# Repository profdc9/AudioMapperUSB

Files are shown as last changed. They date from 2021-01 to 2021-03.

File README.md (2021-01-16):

# AudioMapper USB by Daniel Marks

This project is to develop a simple device for characterizing the audio characteristics of a room.  It is intended to be used 

It is based on the PCM2900/PCM2902 TI USB CODEC DAC/ADC.  It has the following features:

- Amplification for two microphone inputs (up to a gain of 125 or 42 dB gain).  The gain stages may be jumpered out if desired to provide a standard line input.
- Phantom power provided to microphone inputs (10 kohm resistor for 5 volts) so that electret or dynamic microphones may be used.
- DAC is 44.1 kHz/48 kHz 16-bit stereo output.
- ADC is 44.1 kHz/48 kHz 16-bit stereo input.
- Can sample the outputs back to the input for synchronizing the audio output signal to the audio input signal.
- Several boards may be chained together to synchronize them.
- A provision for external power input so that the USB power noise (especially USB traffic) does not produce noise on the microphone inputs.  It is recommended that a 9-12 VDC linear power supply is used.
- SPDIF input and outputs.
- Feedback resistors can be surface mount or through hole for easy gain adjustments.

The kicad files and gerbers are provided.  The project is licensed under the Creative Common License, CC-BY-SA 4.0.

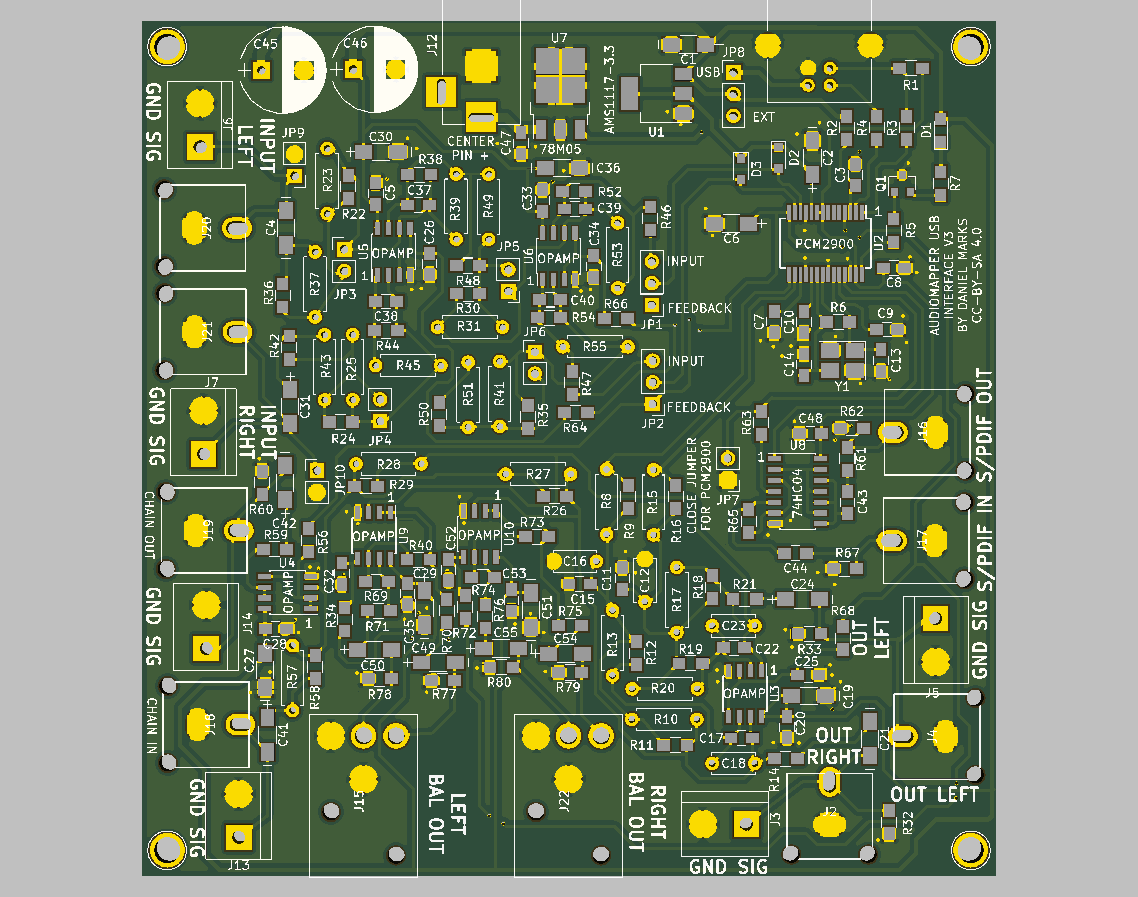
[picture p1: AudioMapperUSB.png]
PCB


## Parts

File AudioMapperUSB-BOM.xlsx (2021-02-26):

Comment | Designator | Footprint | LCSC
18 pF | C14,C13 | Capacitors_SMD:C_0805_HandSoldering | C1797
1.5 nF | C15,C11 | Capacitors_SMD:C_0805_HandSoldering | C1717
330 pF | C17,C22 | Capacitors_SMD:C_0805_HandSoldering | C51207
NO | C18,C16,C23,C12 | Capacitors_THT:C_Disc_D5.0mm_W2.5mm_P5.00mm | C51207
10 uF | C2,C1,C6,C4,C19,C21,C24,C27,C30,C31,C36,C42,C41 | AudioMapperUSB:CP_1206_HandSoldering | C7171
1 uF | C3,C8,C10,C7,C20,C25,C28,C5,C34,C33,C9,C43,C44,C47,C48,C26 | Capacitors_SMD:C_0805_HandSoldering | C28323
22 pF | C38,C37 | Capacitors_SMD:C_0805_HandSoldering | C1804
100 pF | C40,C39 | Capacitors_SMD:C_0805_HandSoldering | C1790
1000 uF | C46,C45 | Capacitors_THT:CP_Radial_D10.0mm_P5.00mm
LED | D1 | LEDs:LED_0805_HandSoldering | C84256
1N4148WS | D2,D3 | Diodes_SMD:D_SOD-323_HandSoldering | C2128
USB_B | J1 | Connectors:USB_B
Jack-DC | J12 | Connectors:BARREL_JACK
Audio-Jack-2 | J2,J4,J16,J17,J18,J19,J20,J21 | AudioMapperUSB:RCAConnectorCommon
Conn_01x02 | J3,J5,J6,J7,J13,J14 | Connectors_Terminal_Blocks:TerminalBlock_bornier-2_P5.08mm
Conn_01x01 | J8,J10,J11,J9 | Connectors:1pin
Jumper_NC_Dual | JP2,JP1,JP8 | Pin_Headers:Pin_Header_Straight_1x03_Pitch2.54mm
Jumper_NC_Small | JP7,JP3,JP4,JP5,JP6 | Pin_Headers:Pin_Header_Straight_1x02_Pitch2.54mm
Jumper_NO_Small | JP9,JP10 | Pin_Headers:Pin_Header_Straight_1x02_Pitch2.54mm
SS8550 | Q1 | TO_SOT_Packages_SMD:SOT-23 | C8542
1k5 | R1,R5,R7,R46,R47,R56 | Resistors_SMD:R_0805_HandSoldering | C4310
3k9 | R12,R19 | Resistors_SMD:R_0805_HandSoldering | C17614
100R | R14,R21,R59,R62,R67 | Resistors_SMD:R_0805_HandSoldering | C17408
2R2 | R2 | Resistors_SMD:R_0805_HandSoldering | C17521
10k | R26,R29,R65 | Resistors_SMD:R_0805_HandSoldering | C17414
22R | R3,R4 | Resistors_SMD:R_0805_HandSoldering | C17561
18k | R30,R35 | Resistors_SMD:R_0805_HandSoldering | C17506
4k7 | R36,R42,R48,R50,R58 | Resistors_SMD:R_0805_HandSoldering | C17673
100k | R38,R44,R22,R24,R64,R66,R68 | Resistors_SMD:R_0805_HandSoldering | C17407
22k | R52,R54 | Resistors_SMD:R_0805_HandSoldering | C17560
1M | R6,R32,R33,R60 | Resistors_SMD:R_0805_HandSoldering | C17514
220R | R61 | Resistors_SMD:R_0805_HandSoldering | C17557
1k | R63 | Resistors_SMD:R_0805_HandSoldering | C17513
NO | R8,R13,R10,R15,R20,R17,R27,R28,R37,R39,R43,R45,R49,R53,R51,R55,R57,R23,R25,R31,R41 | Resistors_THT:R_Axial_DIN0207_L6.3mm_D2.5mm_P7.62mm_Horizontal
12K | R9,R11,R16,R18 | Resistors_SMD:R_0805_HandSoldering | C17444
AMS1117-3.3 | U1 | TO_SOT_Packages_SMD:SOT-223-3_TabPin2 | C6186
PCM2900 | U2 | Housings_SSOP:SSOP-28_5.3x10.2mm_Pitch0.65mm | C180425
OPA2170 | U3,U4,U5,U6 | Housings_SOIC:SOIC-8_3.9x4.9mm_Pitch1.27mm | C157708 (https://lcsc.com/product-detail/Low-Noise-OpAmps_Gainsil-GS8722-SR_C157708.html/?href=jlc-SMT)
KA78M05_TO252 | U7 | TO_SOT_Packages_SMD:TO-252-3_TabPin2 | C58069
74HC04 | U8 | Housings_SOIC:SOIC-14_3.9x8.7mm_Pitch1.27mm | C5590
12 MHz | Y1 | Crystals:Crystal_SMD_3225-4pin_3.2x2.5mm_HandSoldering | C9002

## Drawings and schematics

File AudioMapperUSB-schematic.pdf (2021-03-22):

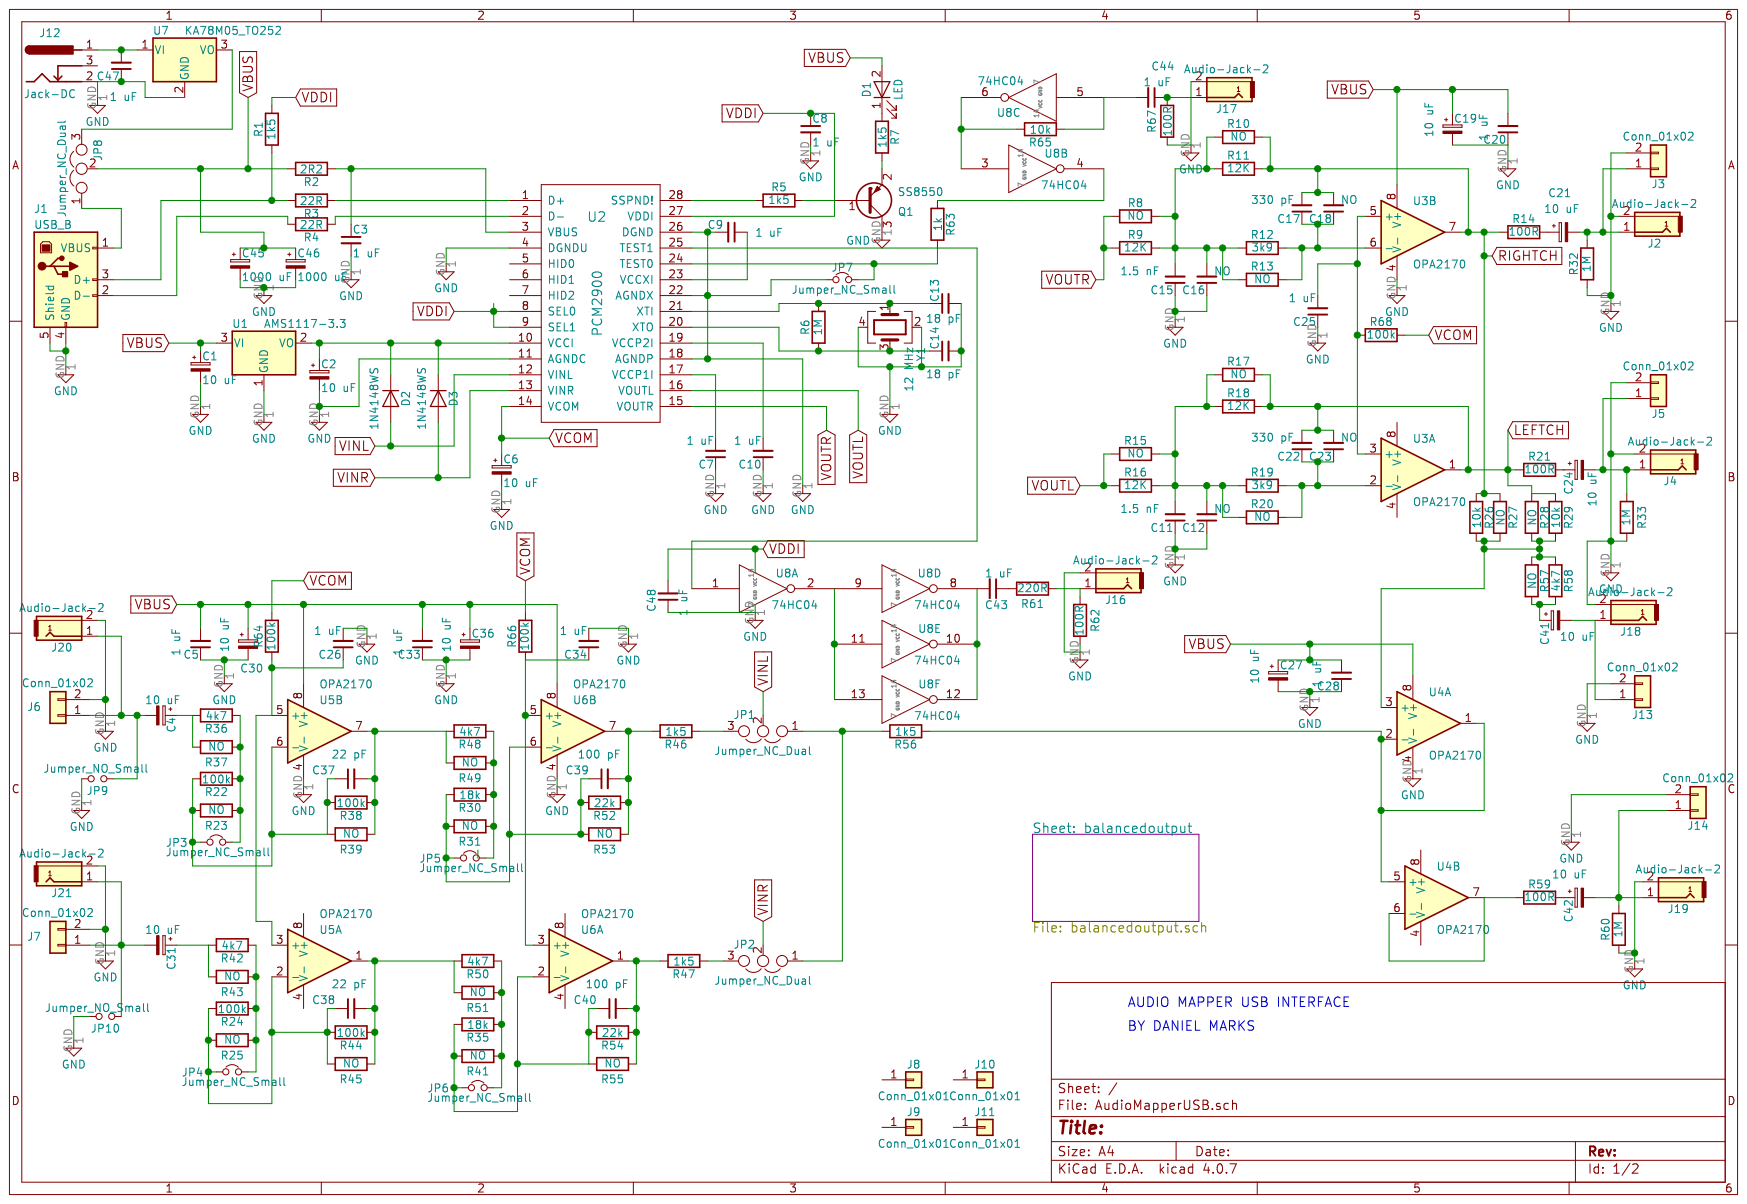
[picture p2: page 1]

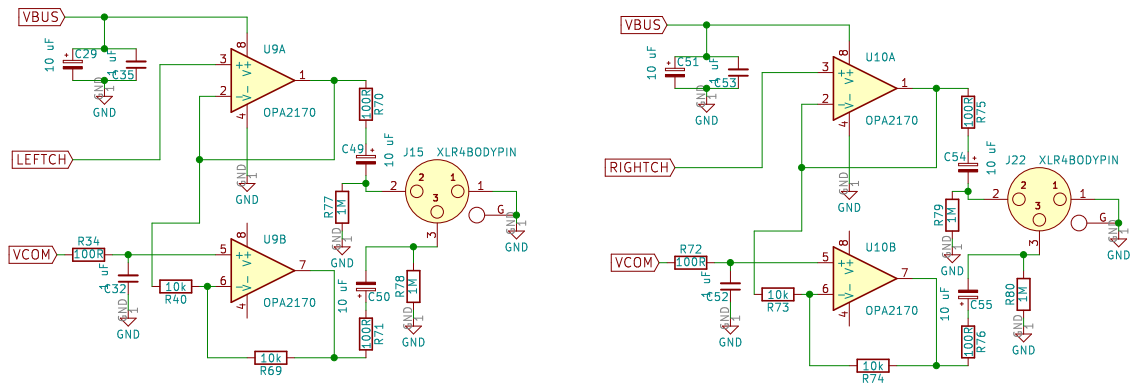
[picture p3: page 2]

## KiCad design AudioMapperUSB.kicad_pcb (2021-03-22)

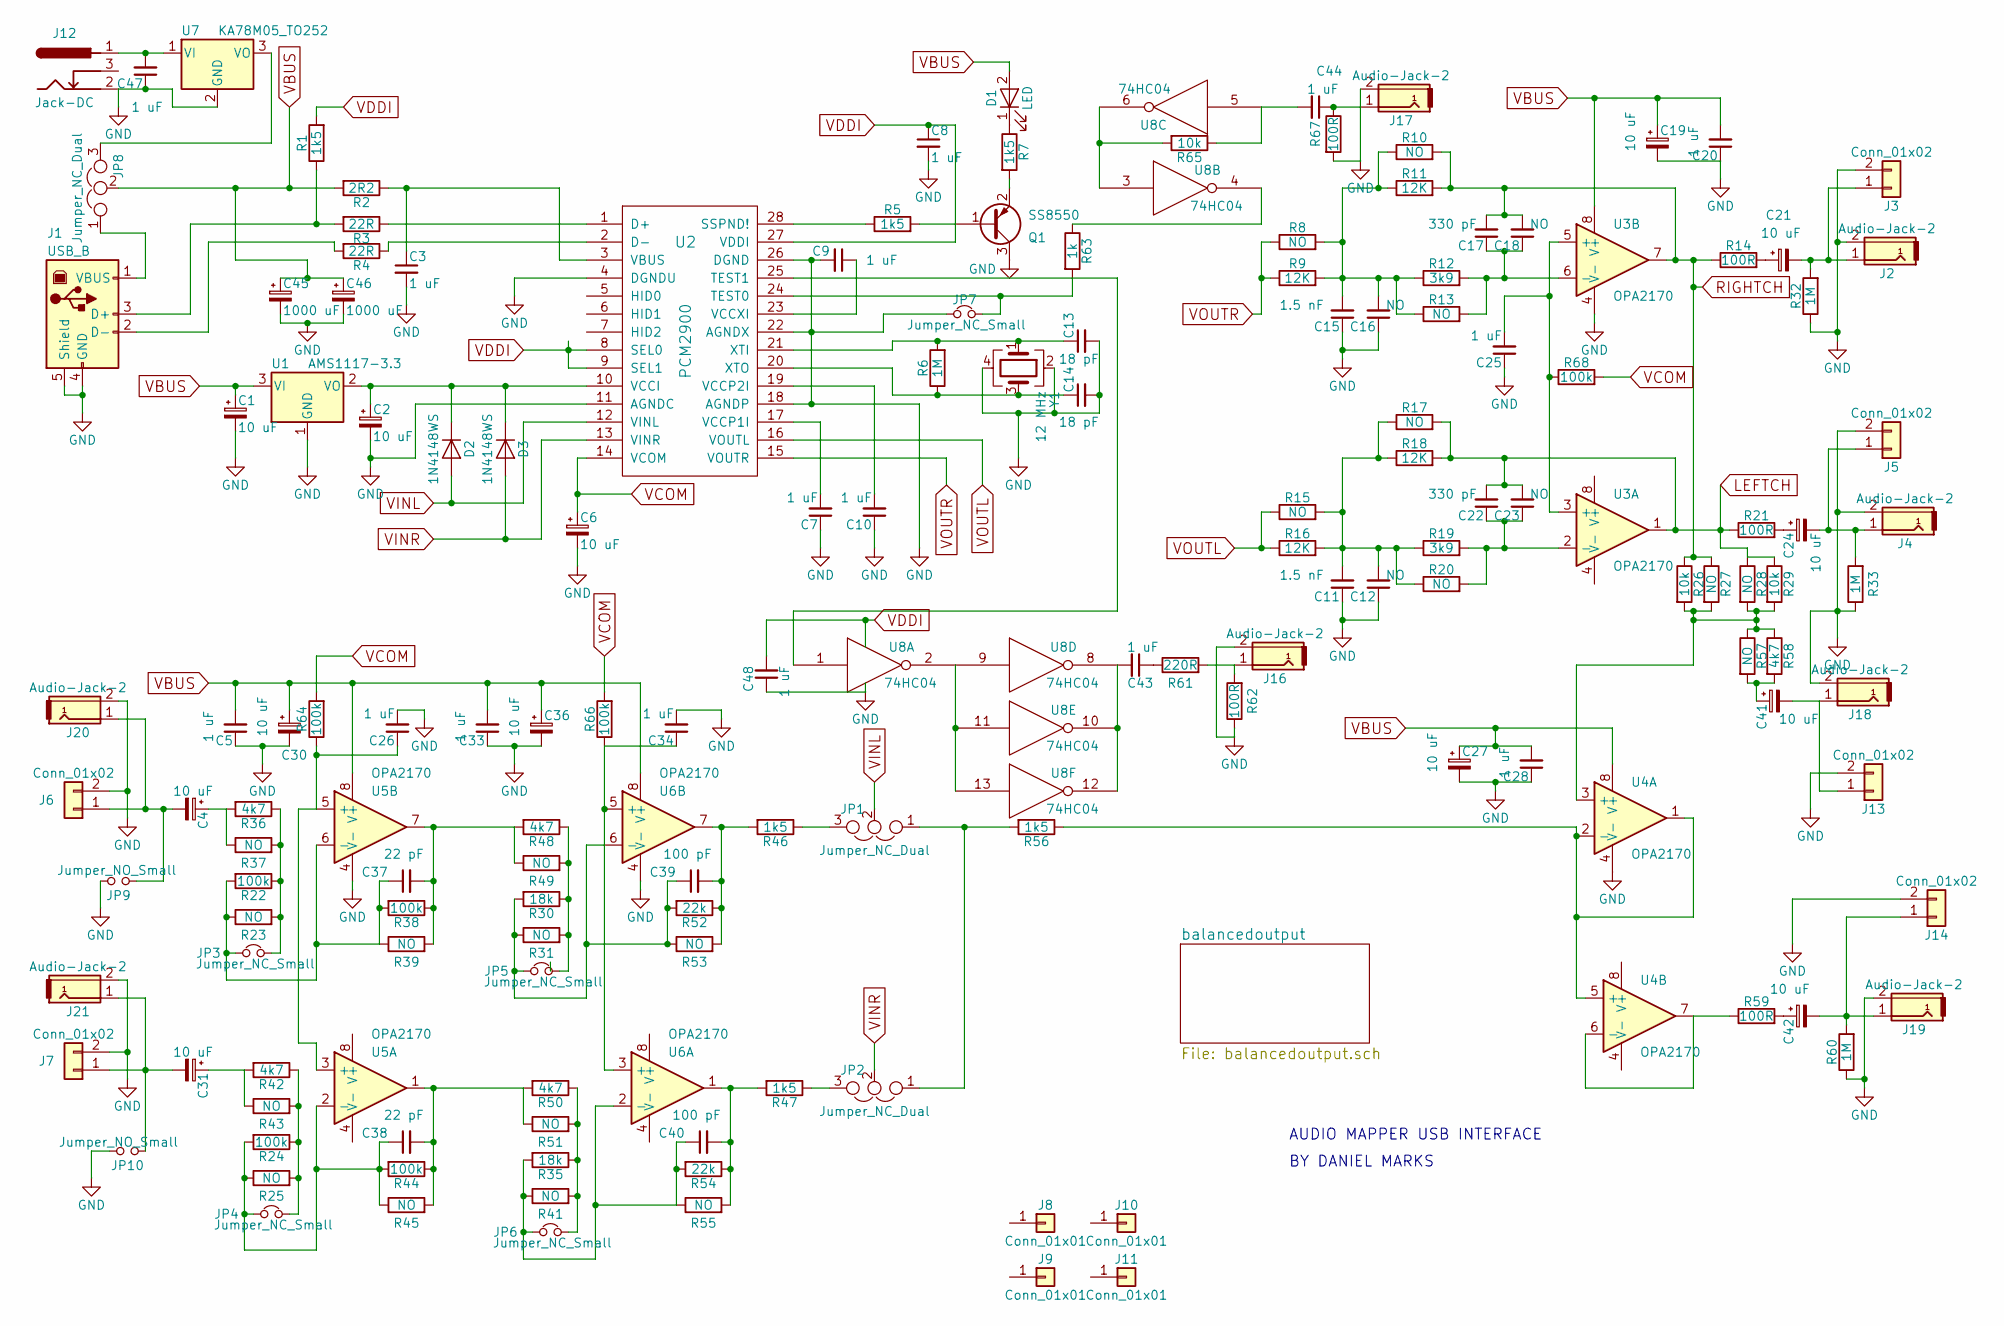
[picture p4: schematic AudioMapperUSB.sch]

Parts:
C1, C2, C4, C6, C19, C21, C24, C27, C30, C31, C36, C41, C42: 10 uF; CP_1206_HandSoldering; LCSC C7171
C3, C5, C7, C8, C9, C10, C20, C25, C26, C28, C33, C34, C43, C44, C47, C48: 1 uF; C_0805_HandSoldering; LCSC C28323
C11, C15: 1.5 nF; C_0805_HandSoldering; LCSC C1717
C12, C16: NO; C_Disc_D5.0mm_W2.5mm_P5.00mm
C13, C14: 18 pF; C_0805_HandSoldering; LCSC C1797
C17, C22: 330 pF; C_0805_HandSoldering; LCSC C51207
C18, C23: NO; C_Disc_D5.0mm_W2.5mm_P5.00mm; LCSC C51207
C37, C38: 22 pF; C_0805_HandSoldering; LCSC C1804
C39, C40: 100 pF; C_0805_HandSoldering; LCSC C1790
C45, C46: 1000 uF; CP_Radial_D10.0mm_P5.00mm
D1: LED; LED_0805_HandSoldering; LCSC C84256
D2, D3: 1N4148WS; D_SOD-323_HandSoldering; LCSC C2128
J1: USB_B
J2, J4, J16, J17, J18, J19, J20, J21: Audio-Jack-2; RCAConnectorCommon
J3, J5, J6, J7, J13, J14: Conn_01x02; TerminalBlock_bornier-2_P5.08mm
J8, J9, J10, J11: Conn_01x01; 1pin
J12: Jack-DC; BARREL_JACK
JP1, JP2, JP8: Jumper_NC_Dual; Pin_Header_Straight_1x03_Pitch2.54mm
JP3, JP4, JP5, JP6, JP7: Jumper_NC_Small; Pin_Header_Straight_1x02_Pitch2.54mm
JP9, JP10: Jumper_NO_Small; Pin_Header_Straight_1x02_Pitch2.54mm
Q1: SS8550; SOT-23; LCSC C8542
R1, R5, R7, R46, R47, R56: 1k5; R_0805_HandSoldering; LCSC C4310
R2: 2R2; R_0805_HandSoldering; LCSC C17521
R3, R4: 22R; R_0805_HandSoldering; LCSC C17561
R6, R32, R33, R60: 1M; R_0805_HandSoldering; LCSC C17514
R8, R10, R13, R15, R17, R20, R23, R25, R27, R28, R31, R37, R39, R41, R43, R45, R49, R51, R53, R55, R57: NO; R_Axial_DIN0207_L6.3mm_D2.5mm_P7.62mm_Horizontal
R9, R11, R16: 12K; R_0805_HandSoldering; LCSC C17444
R12, R19: 3k9; R_0805_HandSoldering; LCSC C17614
R14, R21, R59, R62, R67: 100R; R_0805_HandSoldering; LCSC C17408
R18: 12K; R_0805_HandSoldering; LCSC C17614
R22, R24, R38, R44, R64, R66, R68: 100k; R_0805_HandSoldering; LCSC C17407
R26, R29, R65: 10k; R_0805_HandSoldering; LCSC C17414
R30, R35: 18k; R_0805_HandSoldering; LCSC C17506
R36, R42, R48, R50, R58: 4k7; R_0805_HandSoldering; LCSC C17673
R52, R54: 22k; R_0805_HandSoldering; LCSC C17560
R61: 220R; R_0805_HandSoldering; LCSC C17557
R63: 1k; R_0805_HandSoldering; LCSC C17513
U1: AMS1117-3.3; SOT-223-3_TabPin2; LCSC C6186
U2: PCM2900; SSOP-28_5.3x10.2mm_Pitch0.65mm; LCSC C180425
U3, U4, U5, U6: OPA2170; SOIC-8_3.9x4.9mm_Pitch1.27mm; LCSC C56285
U7: KA78M05_TO252; TO-252-3_TabPin2; LCSC C58069
U8: 74HC04; SOIC-14_3.9x8.7mm_Pitch1.27mm; LCSC C5590
Y1: 12 MHz; Crystal_SMD_3225-4pin_3.2x2.5mm_HandSoldering; LCSC C9002

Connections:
GND: C1.2, C2.2, C3.2, C5.1, C6.2, C7.1, C8.2, C9.2, C10.1, C11.1, C12.1, C13.2, C14.2, C15.1, C16.1, C19.2, C20.1, C25.1, C26.2, C27.2, C28.1, C30.2, C33.1, C34.2, C36.2, C45.2, C46.2, C47.1, C48.1, J1.4 (GND), J1.5 (Shield), J2.2, J3.2, J4.2, J5.2, J6.2, J7.2, J12.2, J13.2, J14.2, J16.2, J17.2, J18.2, J19.2, J20.2, J21.2, JP7.1, JP9.2, JP10.2, Q1.3 (C), R32.1, R33.1, R60.1, R62.1, R67.2, U1.1 (GND), U2.4 (DGNDU), U2.11 (AGNDC), U2.18 (AGNDP), U2.22 (AGNDX), U2.26 (DGND), U3.4 (V-), U4.4 (V-), U5.4 (V-), U6.4 (V-), U7.2 (GND), U8.7 (GND), Y1.2, Y1.4; also elsewhere on the board
LEFTCH: C22.2, C23.2, R17.2, R18.2, R21.1, R28.1, R29.1, U3.1; also elsewhere on the board
unnamed: C2.1, D2.1 (K), D3.1 (K), U1.2 (VO), U2.10 (VCCI)
unnamed: C3.1, R2.1, U2.3 (VBUS)
unnamed: C4.1, R36.2, R37.1
unnamed: C4.2, J6.1, J20.1, JP9.1
unnamed: C7.2, U2.17 (VCCP1I)
unnamed: C9.1, U2.23 (VCCXI)
unnamed: C10.2, U2.19 (VCCP2I)
unnamed: C11.2, C12.2, R15.2, R16.2, R17.1, R18.1, R19.1, R20.1
unnamed: C13.1, R6.2, U2.21 (XTI), Y1.1
unnamed: C14.1, R6.1, U2.20 (XTO), Y1.3
unnamed: C15.2, C16.2, R8.2, R9.2, R10.1, R11.1, R12.1, R13.1
unnamed: C17.1, C18.1, R12.2, R13.2, U3.6 (-)
unnamed: C21.1, R14.2
unnamed: C21.2, J2.1, J3.1, R32.2
unnamed: C22.1, C23.1, R19.2, R20.2, U3.2 (-)
unnamed: C24.1, R21.2
unnamed: C24.2, J4.1, J5.1, R33.2
unnamed: C25.2, R68.1, U3.3 (+), U3.5 (+)
unnamed: C26.1, R64.1, U5.3 (+), U5.5 (+)
unnamed: C31.1, R42.2, R43.1
unnamed: C31.2, J7.1, J21.1, JP10.1
unnamed: C34.1, R66.1, U6.3 (+), U6.5 (+)
unnamed: C37.1, JP3.1, R22.2, R23.1, R38.2, R39.1, U5.6 (-)
unnamed: C37.2, R38.1, R39.2, R48.2, R49.1, U5.7
unnamed: C38.1, JP4.1, R24.2, R25.1, R44.2, R45.1, U5.2 (-)
unnamed: C38.2, R44.1, R45.2, R50.2, R51.1, U5.1
unnamed: C39.1, JP5.1, R30.2, R31.1, R52.2, R53.1, U6.6 (-)
unnamed: C39.2, R46.2, R52.1, R53.2, U6.7
unnamed: C40.1, JP6.1, R35.2, R41.1, R54.2, R55.1, U6.2 (-)
unnamed: C40.2, R47.2, R54.1, R55.2, U6.1
unnamed: C41.1, R57.2, R58.2
unnamed: C41.2, J13.1, J18.1
unnamed: C42.1, R59.2
unnamed: C42.2, J14.1, J19.1, R60.2
unnamed: C43.1, R61.1
unnamed: C43.2, U8.8, U8.10, U8.12
unnamed: C44.1, J17.1, R67.1
unnamed: C44.2, R65.1, U8.5
unnamed: C47.2, J12.1, U7.1 (VI)
unnamed: D1.1 (K), R7.1
unnamed: J1.1 (VBUS), JP8.1
unnamed: J1.2 (D-), R4.2
unnamed: J1.3 (D+), R1.1, R3.2
unnamed: J16.1, R61.2, R62.2
unnamed: JP1.1, JP2.1, R56.2
unnamed: JP1.3, R46.1
unnamed: JP2.3, R47.1
unnamed: JP3.2, R22.1, R23.2, R36.1, R37.2
unnamed: JP4.2, R24.1, R25.2, R42.1, R43.2
unnamed: JP5.2, R30.1, R31.2, R48.1, R49.2
unnamed: JP6.2, R35.1, R41.2, R50.1, R51.2
unnamed: JP7.2, R63.2, U2.24 (TEST0)
unnamed: JP8.3, U7.3 (VO)
unnamed: Q1.1 (B), R5.2
unnamed: Q1.2 (E), R7.2
unnamed: R3.1, U2.1 (D+)
unnamed: R4.1, U2.2 (D-)
unnamed: R5.1, U2.28 (SSPND!)
unnamed: R26.2, R27.2, R28.2, R29.2, R57.1, R58.1, U4.3 (+)
unnamed: R56.1, U4.1, U4.2 (-), U4.5 (+)
unnamed: R59.1, U4.6 (-), U4.7
unnamed: R63.1, U8.4
unnamed: R65.2, U8.3, U8.6
unnamed: U2.25 (TEST1), U8.1
unnamed: U8.2, U8.9, U8.11, U8.13
RIGHTCH: C17.2, C18.2, R10.2, R11.2, R14.1, R26.1, R27.1, U3.7; also elsewhere on the board
VBUS: C1.1, C5.2, C19.1, C20.2, C27.1, C28.2, C30.1, C33.2, C36.1, C45.1, C46.1, D1.2 (A), JP8.2, R2.2, U1.3 (VI), U3.8 (V+), U4.8 (V+), U5.8 (V+), U6.8 (V+); also elsewhere on the board
VCOM: C6.1, R64.2, R66.2, R68.2, U2.14 (VCOM); also elsewhere on the board
VDDI: C8.1, C48.2, R1.2, U2.8 (SEL0), U2.9 (SEL1), U2.27 (VDDI), U8.14 (VCC)
VINL: D2.2 (A), JP1.2, U2.12 (VINL)
VINR: D3.2 (A), JP2.2, U2.13 (VINR)
VOUTL: R15.1, R16.1, U2.16 (VOUTL)
VOUTR: R8.1, R9.1, U2.15 (VOUTR)

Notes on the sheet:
AUDIO MAPPER USB INTERFACE
BY DANIEL MARKS

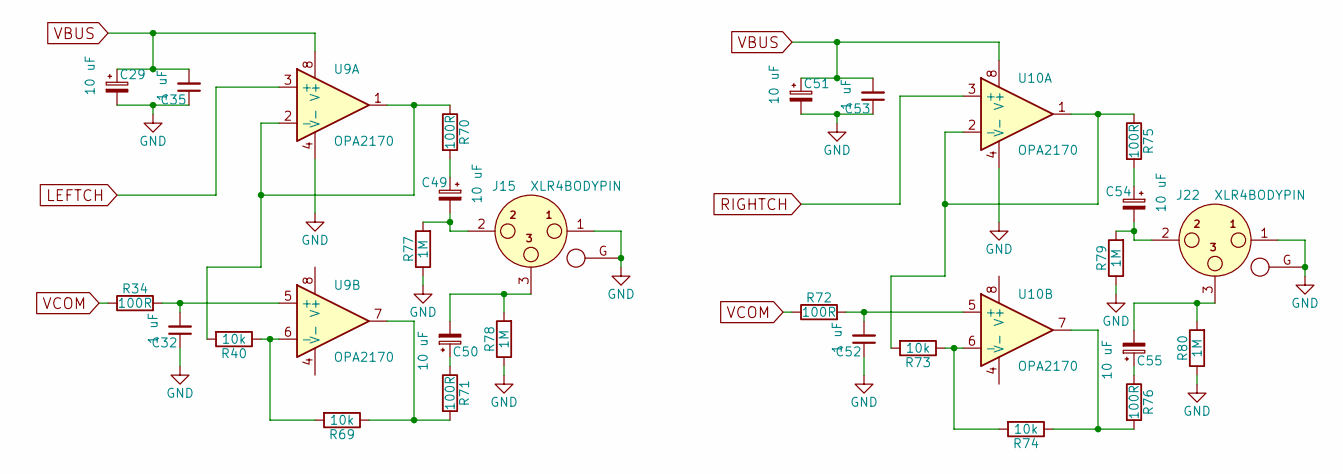
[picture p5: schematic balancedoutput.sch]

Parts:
C29, C49, C50, C51, C54, C55: 10 uF; CP_1206_HandSoldering; LCSC C7171
C32, C35, C52, C53: 1 uF; C_0805_HandSoldering; LCSC C28323
J15, J22: XLR4BODYPIN; IOXLR3MEH
R34, R70, R71, R72, R75, R76: 100R; R_0805_HandSoldering; LCSC C17408
R40, R69, R73, R74: 10k; R_0805_HandSoldering; LCSC C17414
R77, R78, R79, R80: 1M; R_0805_HandSoldering; LCSC C17514
U9, U10: OPA2170; SOIC-8_3.9x4.9mm_Pitch1.27mm; LCSC C56285

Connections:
GND: C29.2, C32.1, C35.1, C51.2, C52.1, C53.1, J15.1, J15.G, J22.1, J22.G, R77.1, R78.1, R79.1, R80.1, U9.4 (V-), U10.4 (V-); also elsewhere on the board
LEFTCH: U9.3 (+); also elsewhere on the board
unnamed: C32.2, R34.2, U9.5 (+)
unnamed: C49.1, R70.2
unnamed: C49.2, J15.2, R77.2
unnamed: C50.1, R71.1
unnamed: C50.2, J15.3, R78.2
unnamed: C52.2, R72.2, U10.5 (+)
unnamed: C54.1, R75.2
unnamed: C54.2, J22.2, R79.2
unnamed: C55.1, R76.1
unnamed: C55.2, J22.3, R80.2
unnamed: R40.1, R69.2, U9.6 (-)
unnamed: R40.2, R70.1, U9.1, U9.2 (-)
unnamed: R69.1, R71.2, U9.7
unnamed: R73.1, R74.2, U10.6 (-)
unnamed: R73.2, R75.1, U10.1, U10.2 (-)
unnamed: R74.1, R76.2, U10.7
RIGHTCH: U10.3 (+); also elsewhere on the board
VBUS: C29.1, C35.2, C51.1, C53.2, U9.8 (V+), U10.8 (V+); also elsewhere on the board
VCOM: R34.1, R72.1; also elsewhere on the board

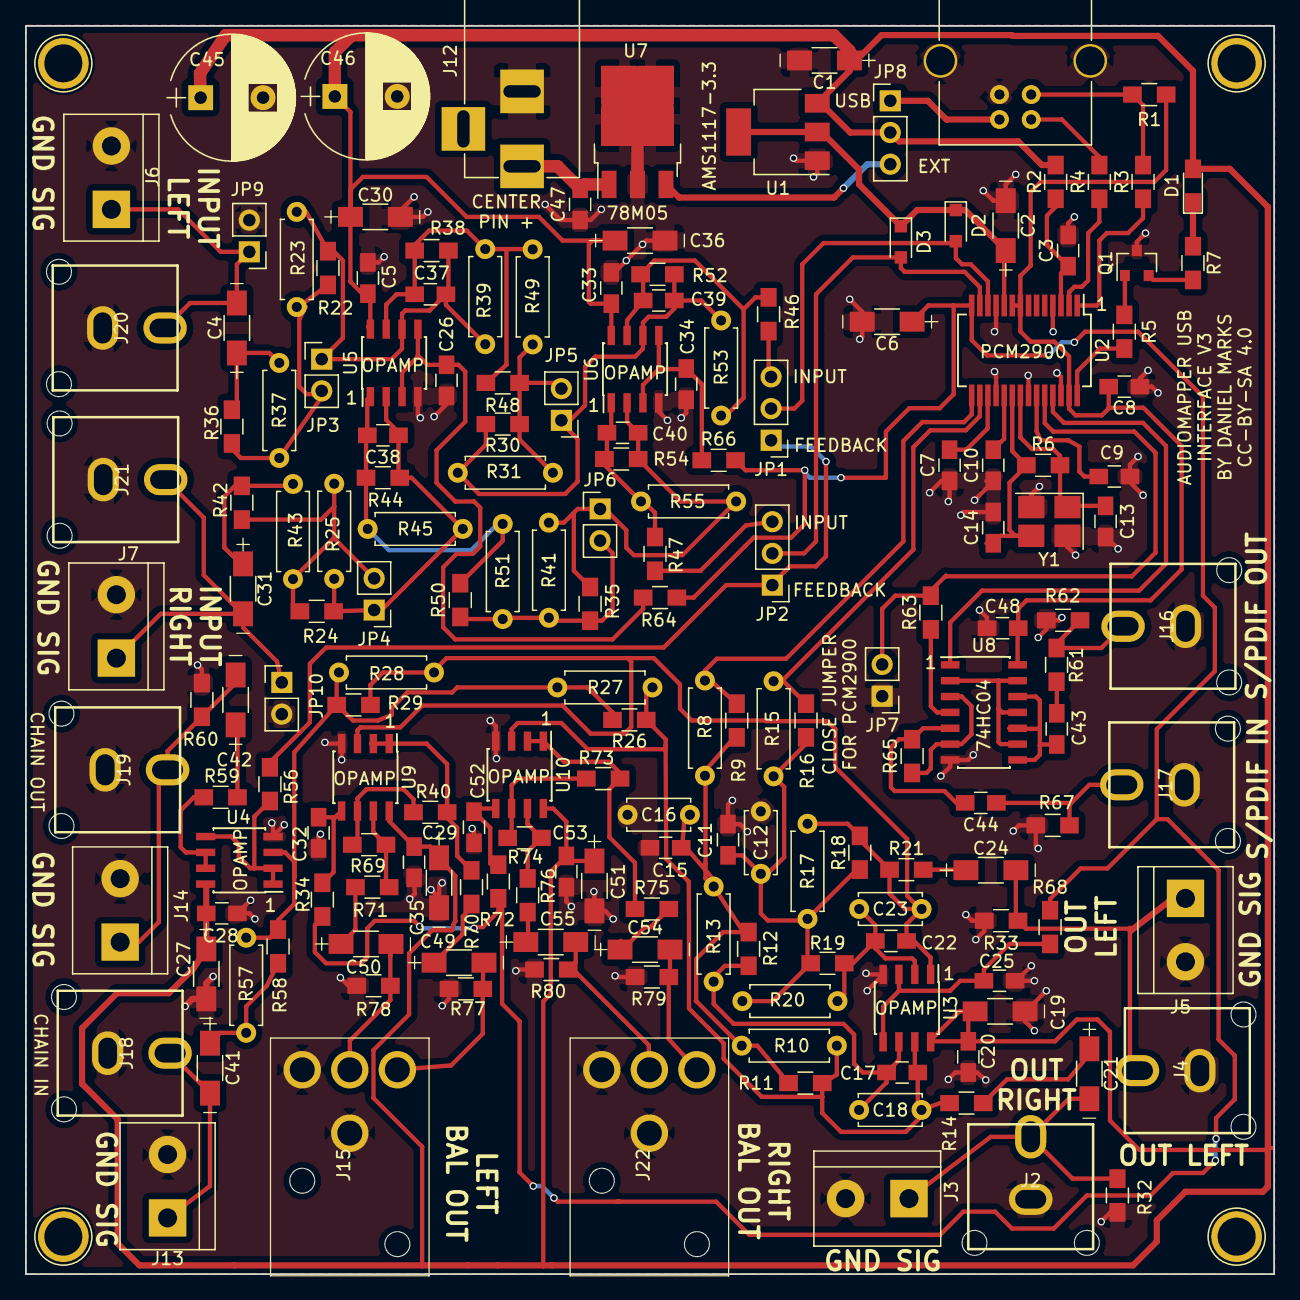
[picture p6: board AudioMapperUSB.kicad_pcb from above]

Board: 2 copper layers, 100.0 x 100.0 mm, 182 parts (0 on the bottom side), 91 nets.

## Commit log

2020-12-29 Added second gain stage to microphone
    [AudioMapperUSB.kicad_pcb, AudioMapperUSB.sch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]
2020-12-31 Added antialiasing on input and SP/DIF input/output
    [AudioMapperUSB.kicad_pcb, AudioMapperUSB.sch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]
2021-01-01 Added ability to chain outputs of two boards together
    [AudioMapperUSB.kicad_pcb, AudioMapperUSB.sch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]
2021-01-03 Added real circuit to interface SPDIF levels to 3.3 V CMOS levels
    [AudioMapperUSB.kicad_pcb, AudioMapperUSB.sch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]
2021-01-03 Added pulldown resistor to input
    [AudioMapperUSB.kicad_pcb, AudioMapperUSB.sch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]
2021-01-06 Fixed backward polarity audio connectors. Duh.
    [AudioMapperUSB.kicad_pcb, AudioMapperUSB.sch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]
2021-01-15 Added external power
    [AudioMapperUSB-BOM.xlsx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]
2021-01-16 Use inverter for SPDIF
    [AudioMapperUSB-B.Cu.gbr, AudioMapperUSB-B.Mask.gbr, AudioMapperUSB-B.SilkS.gbr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]
2021-01-17 Fixed problem with VCOM leaking into input audio
    [AudioMapperUSB-B.Cu.gbr, AudioMapperUSB-B.Mask.gbr, AudioMapperUSB-B.SilkS.gbr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]
2021-01-20 Added isolation between phantom power in mic channels
    [AudioMapperUSB-B.Cu.gbr, AudioMapperUSB-B.Mask.gbr, AudioMapperUSB-B.SilkS.gbr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]
2021-02-01 JLCPCB order 2021-01-31
    [AudioMapperUSB-BOM.xlsx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]
2021-02-11 Added source code of Audiomapper
    [AudioMapperUSB-B.Cu.gbr, AudioMapperUSB-B.Mask.gbr, AudioMapperUSB-B.SilkS.gbr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]
2021-02-26 Fixed JLCPCB BOM/placement
    [AudioMapperUSB-BOM.xlsx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]
2021-03-22 Added balanced outputs
    [AudioMapperUSB-B.Cu.gbr, AudioMapperUSB-B.Mask.gbr, AudioMapperUSB-B.SilkS.gbr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]
